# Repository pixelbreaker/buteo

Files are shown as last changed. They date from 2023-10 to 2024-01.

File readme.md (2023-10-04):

# Buteo

### A unibody split 30 key keyboard (23332 layout) with Cirque trackpad and encoder.

This is the first PCB I have ever designed, and it has been a really fun experience learning both KiCAD and Fusion 360.

I got the PCB made at JLCPCB, gerber files are in `buteo-mx/gerbers.zip`.

Case files (STLs and STEP) are also included.

I haven't written the firmware yet...

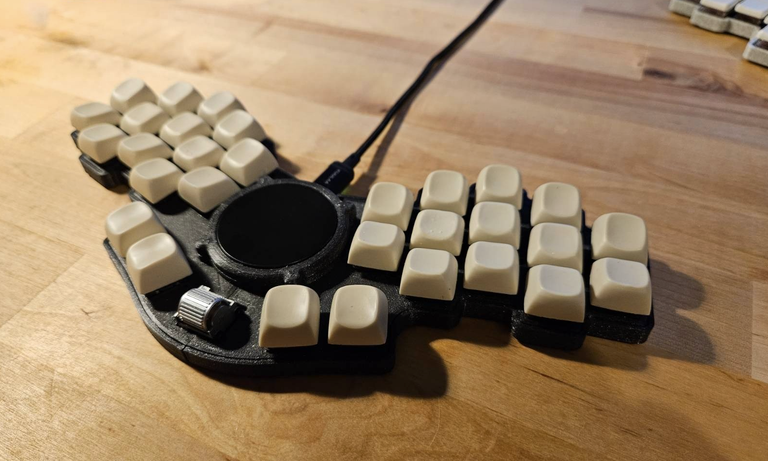
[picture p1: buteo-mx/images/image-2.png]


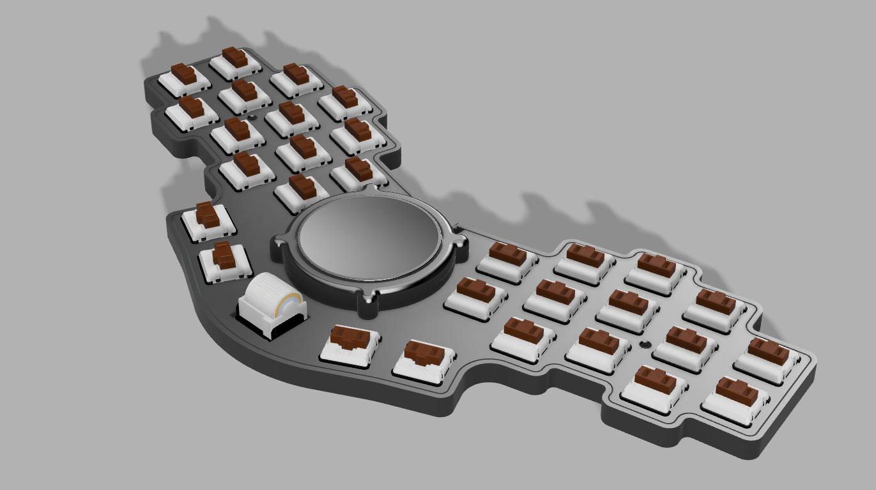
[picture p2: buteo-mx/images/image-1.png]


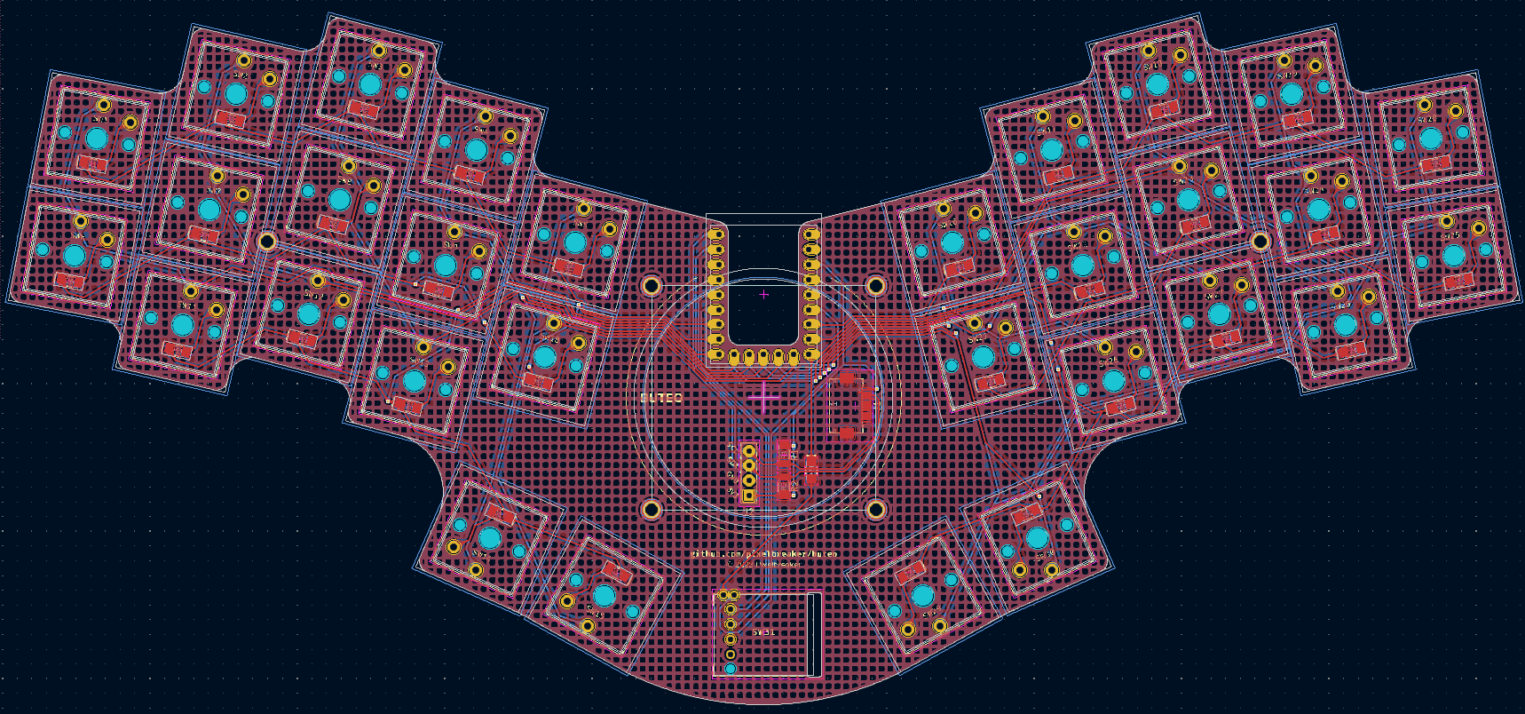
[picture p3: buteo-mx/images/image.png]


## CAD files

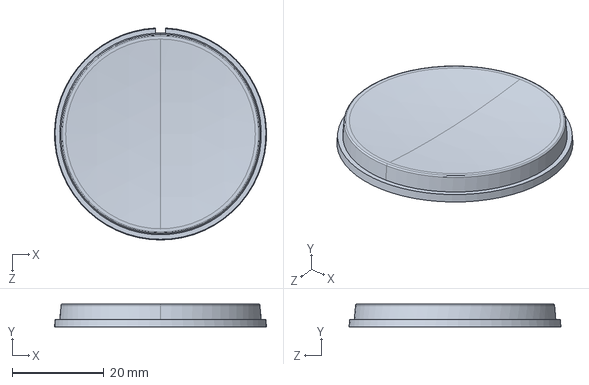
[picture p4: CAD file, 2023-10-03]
buteo-mx-azoteq/assets/50-90-00_Rev_C_Overlay.STEP
46.1 x 5.00 x 46.1 mm

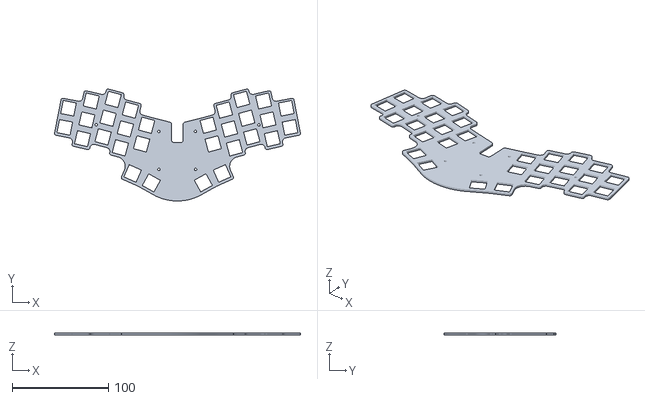
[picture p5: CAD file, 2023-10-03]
buteo-mx-azoteq/Body1.stl
255.5 x 116.3 x 2.00

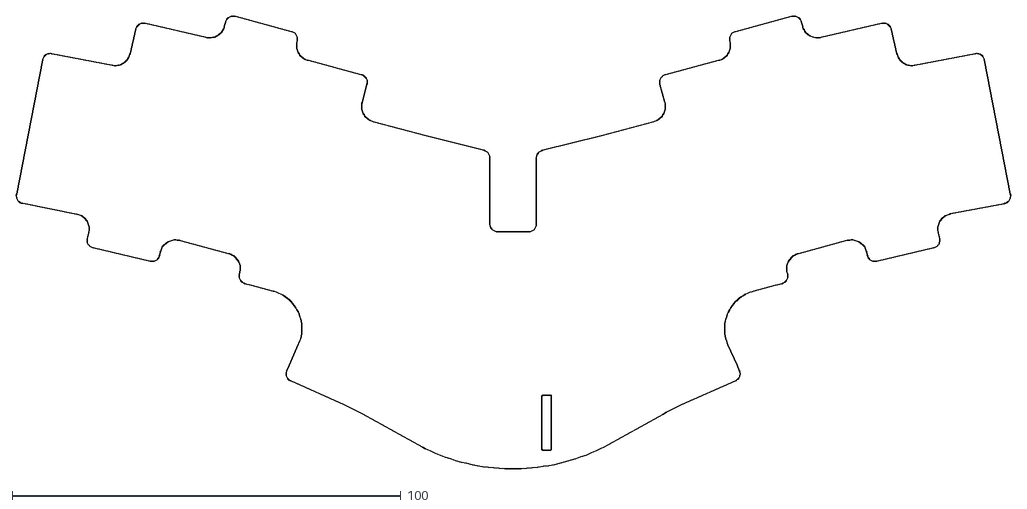
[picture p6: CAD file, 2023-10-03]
buteo-mx-azoteq/dxfs/buteo-mx-Edge_Cuts.dxf
255.6 x 116.4

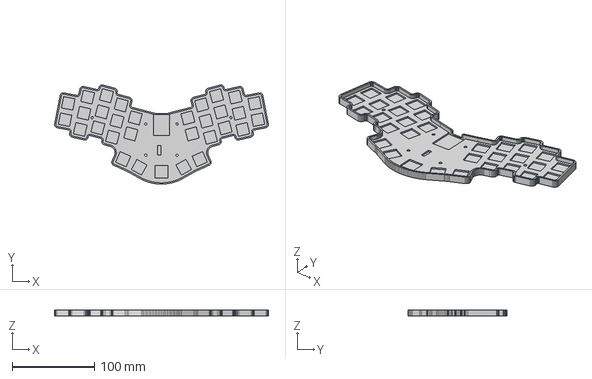
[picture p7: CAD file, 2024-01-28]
buteo-mx-azoteq/stls/Base.step
259.6 x 120.4 x 7.00 mm

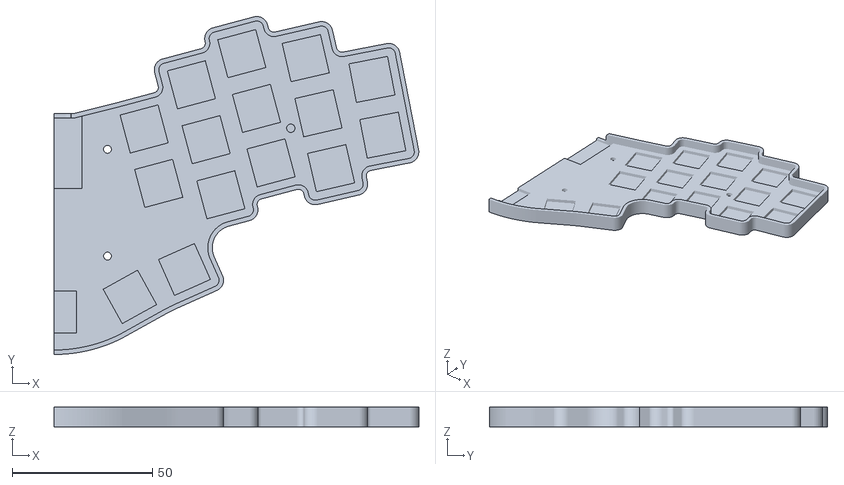
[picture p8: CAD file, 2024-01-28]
buteo-mx/stls/base-right.stl
129.9 x 120.4 x 7.00

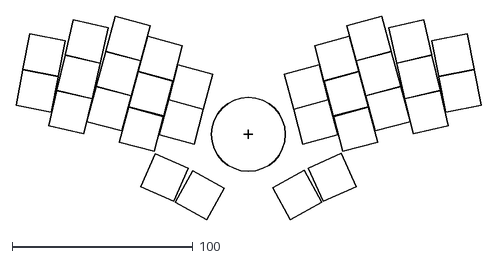
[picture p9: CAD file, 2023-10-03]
buteo-mx-azoteq/dxfs/buteo-mx-User_2.dxf
257.4 x 112.5

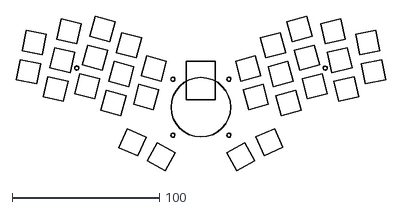
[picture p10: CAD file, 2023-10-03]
buteo-mx-azoteq/dxfs/buteo-mx-User_1.dxf
250.4 x 104.8

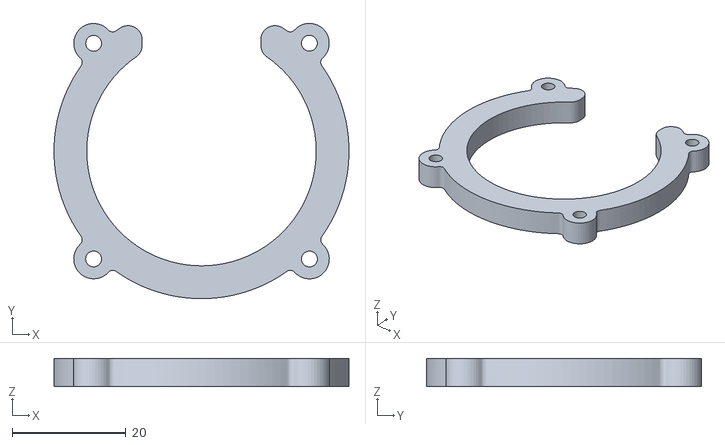
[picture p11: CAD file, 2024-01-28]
buteo-mx-azoteq/stls/trackpad-lower-5mm.stl
51.9 x 48.5 x 5.00

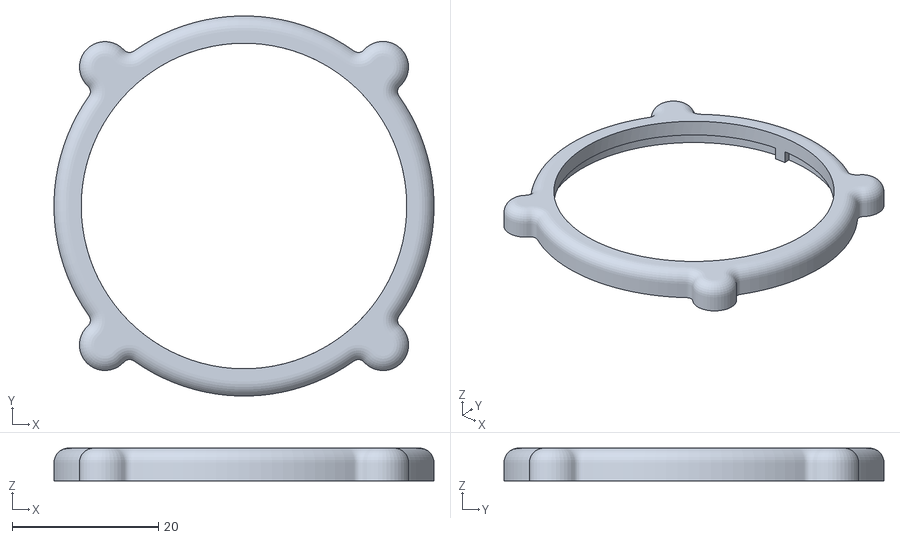
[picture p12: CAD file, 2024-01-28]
buteo-mx/stls/trackpad-upper.stl
51.9 x 51.9 x 4.50

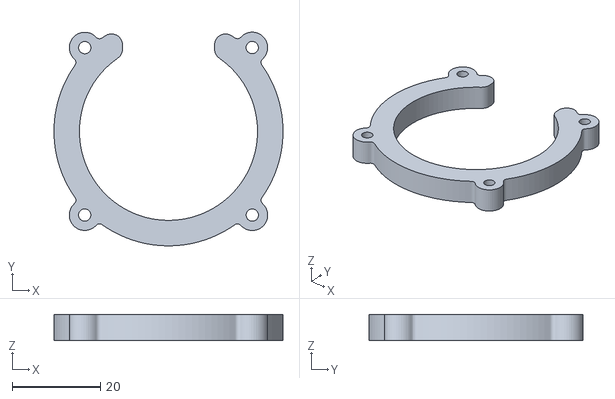
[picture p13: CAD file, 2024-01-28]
buteo-mx-azoteq/stls/trackpad-lower-6mm.stl
51.9 x 48.5 x 6.00

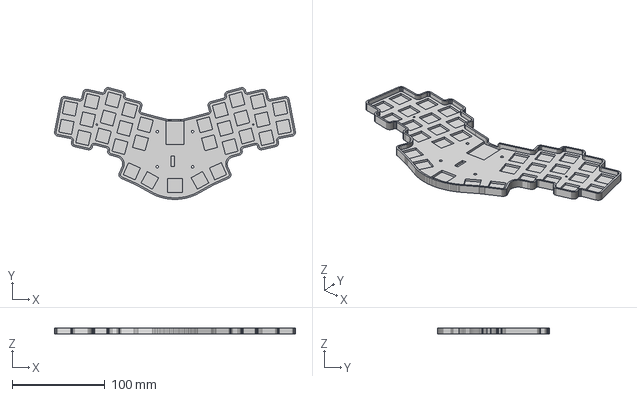
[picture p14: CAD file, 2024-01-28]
buteo-mx-azoteq/stls/BaseCNC.step
259.6 x 120.4 x 7.00 mm

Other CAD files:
buteo-mx/stls/base-left.stl
buteo-mx-azoteq/stls/base-left.stl
buteo-mx-azoteq/stls/base.stl.stl
buteo-mx/stls/base.stl.stl
buteo-mx-azoteq/stls/plate-left.stl
buteo-mx-azoteq/stls/plate-right.stl
buteo-mx-azoteq/stls/trackpad-lower.stl
buteo-mx/stls/trackpad-lower.stl

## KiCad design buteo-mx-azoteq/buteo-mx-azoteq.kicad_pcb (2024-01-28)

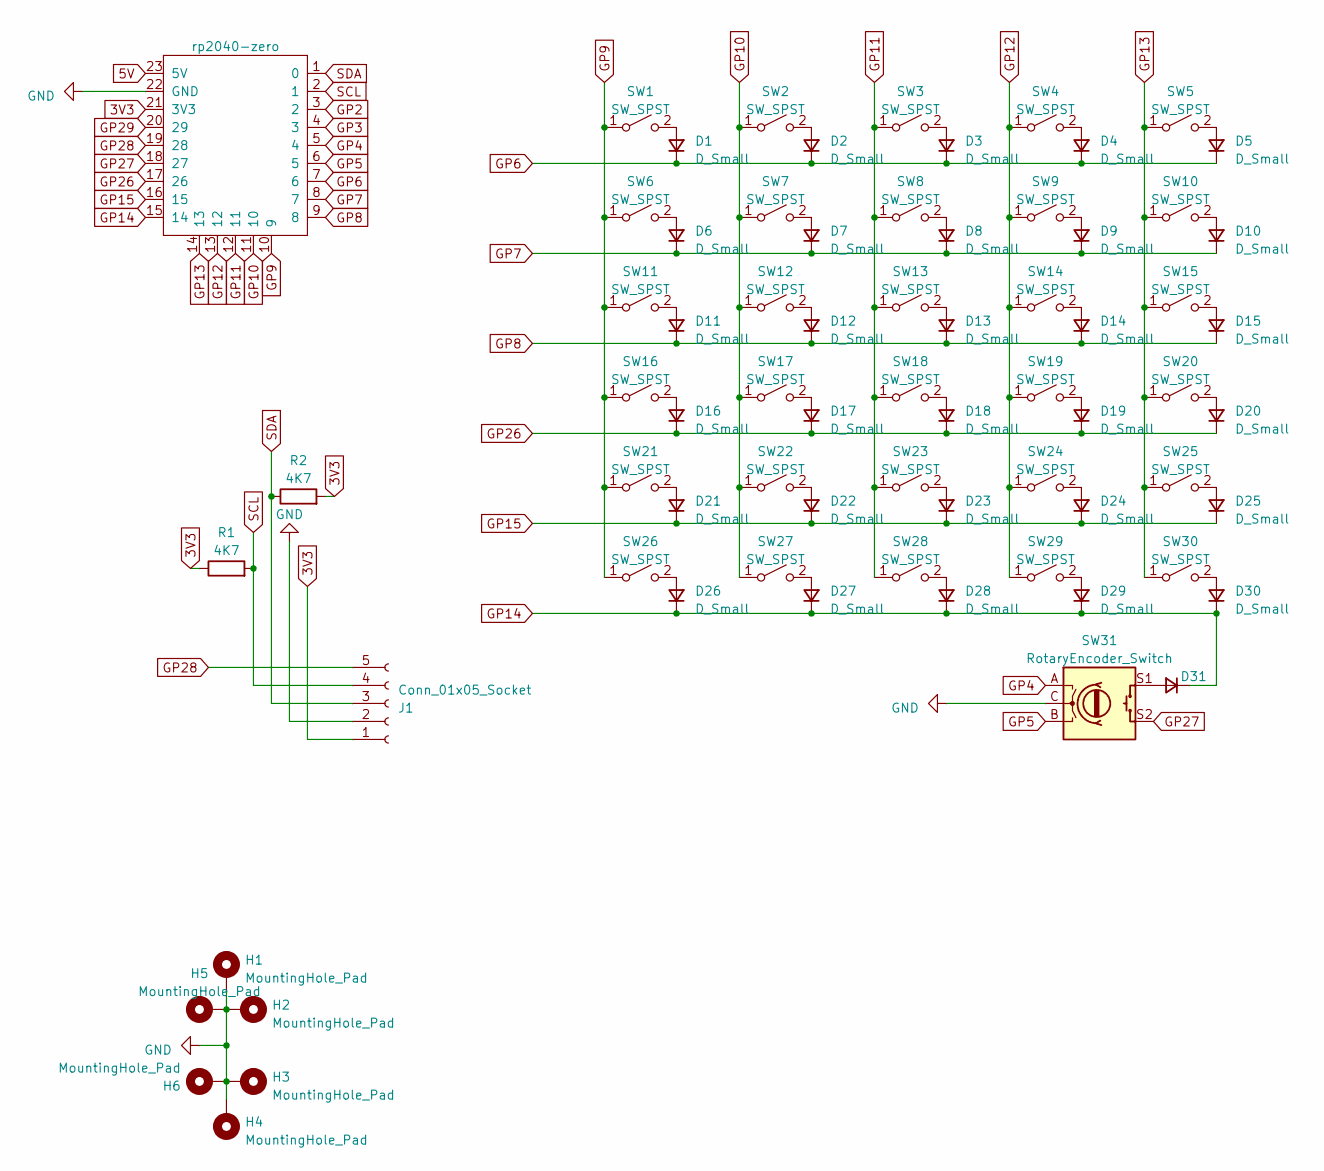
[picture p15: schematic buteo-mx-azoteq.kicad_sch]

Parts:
D1, D2, D3, D4, D5, D6, D7, D8, D9, D10, D11, D12, D13, D14, D15, D16, D17, D18, D19, D20, D21, D22, D23, D24, D25, D26, D27, D28, D29, D30, D31: D_Small; D_1206_3216Metric_Pad1.42x1.75mm_HandSolder
H1, H2, H3, H4, H5, H6: MountingHole_Pad; MountingHole_2.2mm_M2_ISO7380_Pad_TopBottom
J1: Conn_01x05_Socket; PinHeader_1x05_P2.54mm_Vertical
R1, R2: 4K7; R_1206_3216Metric_Pad1.30x1.75mm_HandSolder
RZ1: rp2040-zero; rp2040-zero-tht
SW1, SW2, SW3, SW4, SW5, SW6, SW7, SW8, SW9, SW10, SW11, SW12, SW13, SW14, SW15, SW16, SW17, SW18, SW19, SW20, SW21, SW22, SW23, SW24, SW25, SW26, SW27, SW28, SW29, SW30: SW_SPST; SW_Kailh_Choc_V1_1.00u_MX
SW31: RotaryEncoder_Switch; EVQWGD001

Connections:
3V3: J1.1, R1.1, R2.2, RZ1.21 (3V3)
5V: RZ1.23 (5V)
GND: H1.1, H2.1, H3.1, H4.1, H5.1, H6.1, J1.2, RZ1.22 (GND), SW31.C
GP2: RZ1.3 (2)
GP3: RZ1.4 (3)
GP4: RZ1.5 (4), SW31.A
GP5: RZ1.6 (5), SW31.B
GP6: D1.1 (K), D2.1 (K), D3.1 (K), D4.1 (K), D5.1 (K), RZ1.7 (6)
GP7: D6.1 (K), D7.1 (K), D8.1 (K), D9.1 (K), D10.1 (K), RZ1.8 (7)
GP8: D11.1 (K), D12.1 (K), D13.1 (K), D14.1 (K), D15.1 (K), RZ1.9 (8)
GP9: RZ1.10 (9), SW1.1 (A), SW6.1 (A), SW11.1 (A), SW16.1 (A), SW21.1 (A), SW26.1 (A)
GP10: RZ1.11 (10), SW2.1 (A), SW7.1 (A), SW12.1 (A), SW17.1 (A), SW22.1 (A), SW27.1 (A)
GP11: RZ1.12 (11), SW3.1 (A), SW8.1 (A), SW13.1 (A), SW18.1 (A), SW23.1 (A), SW28.1 (A)
GP12: RZ1.13 (12), SW4.1 (A), SW9.1 (A), SW14.1 (A), SW19.1 (A), SW24.1 (A), SW29.1 (A)
GP13: RZ1.14 (13), SW5.1 (A), SW10.1 (A), SW15.1 (A), SW20.1 (A), SW25.1 (A), SW30.1 (A)
GP14: D26.1 (K), D27.1 (K), D28.1 (K), D29.1 (K), D30.1 (K), D31.1 (K), RZ1.15 (14)
GP15: D21.1 (K), D22.1 (K), D23.1 (K), D24.1 (K), D25.1 (K), RZ1.16 (15)
GP26: D16.1 (K), D17.1 (K), D18.1 (K), D19.1 (K), D20.1 (K), RZ1.17 (26)
GP27: RZ1.18 (27), SW31.S2
GP28: J1.5, RZ1.19 (28)
GP29: RZ1.20 (29)
unnamed: D1.2 (A), SW1.2 (B)
unnamed: D2.2 (A), SW2.2 (B)
unnamed: D3.2 (A), SW3.2 (B)
unnamed: D4.2 (A), SW4.2 (B)
unnamed: D5.2 (A), SW5.2 (B)
unnamed: D6.2 (A), SW6.2 (B)
unnamed: D7.2 (A), SW7.2 (B)
unnamed: D8.2 (A), SW8.2 (B)
unnamed: D9.2 (A), SW9.2 (B)
unnamed: D10.2 (A), SW10.2 (B)
unnamed: D11.2 (A), SW11.2 (B)
unnamed: D12.2 (A), SW12.2 (B)
unnamed: D13.2 (A), SW13.2 (B)
unnamed: D14.2 (A), SW14.2 (B)
unnamed: D15.2 (A), SW15.2 (B)
unnamed: D16.2 (A), SW16.2 (B)
unnamed: D17.2 (A), SW17.2 (B)
unnamed: D18.2 (A), SW18.2 (B)
unnamed: D19.2 (A), SW19.2 (B)
unnamed: D20.2 (A), SW20.2 (B)
unnamed: D21.2 (A), SW21.2 (B)
unnamed: D22.2 (A), SW22.2 (B)
unnamed: D23.2 (A), SW23.2 (B)
unnamed: D24.2 (A), SW24.2 (B)
unnamed: D25.2 (A), SW25.2 (B)
unnamed: D26.2 (A), SW26.2 (B)
unnamed: D27.2 (A), SW27.2 (B)
unnamed: D28.2 (A), SW28.2 (B)
unnamed: D29.2 (A), SW29.2 (B)
unnamed: D30.2 (A), SW30.2 (B)
unnamed: D31.2 (A), SW31.S1
SCL: J1.4, R1.2, RZ1.2 (1)
SDA: J1.3, R2.1, RZ1.1 (0)

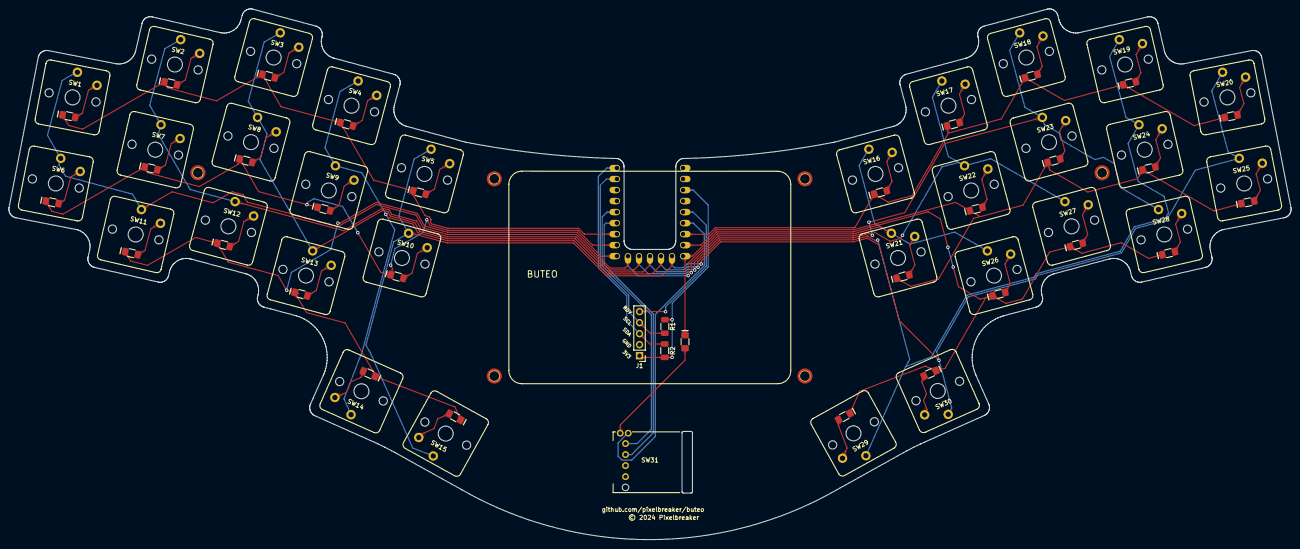
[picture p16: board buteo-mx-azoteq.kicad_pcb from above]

Board: 2 copper layers, 295.6 x 122.4 mm, 72 parts (1 on the bottom side), 50 nets.

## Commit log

2023-08-07 Fix trackpad position
    [buteo.kicad_pcb]
2023-08-09 MX version
    [buteo-mx.kicad_sch, buteo.kicad_pcb, buteo.kicad_sch]
2023-08-09 Fix footprint references and 3D models
    [buteo-mx.kicad_sch]
2023-10-03 V1 MX
    [50-90-00_Rev_C_Overlay.STEP, Base.stl, Body1.stl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]
2023-10-04 clean house
    [50-90-00_Rev_C_Overlay.STEP, Base.stl]
2024-01-28 Add azoteq variant
    [50-90-00_Rev_C_Overlay.STEP, Base.step, BaseCNC.step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]

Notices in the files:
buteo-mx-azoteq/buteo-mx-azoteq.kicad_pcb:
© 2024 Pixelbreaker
